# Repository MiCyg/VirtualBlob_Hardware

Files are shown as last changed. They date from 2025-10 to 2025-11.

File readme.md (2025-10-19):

# Virtual Blob Hardware


[← Back to main repository](https://github.com/MiCyg/VirtualBlob.git)

---

The device consists of three PCBs:
- `MainBoard` – microcontroller and peripheral interfaces
- `PowerBoard` – USB connector and battery charging circuit
- `LedBoard` – LED matrix driven by the MAX7219

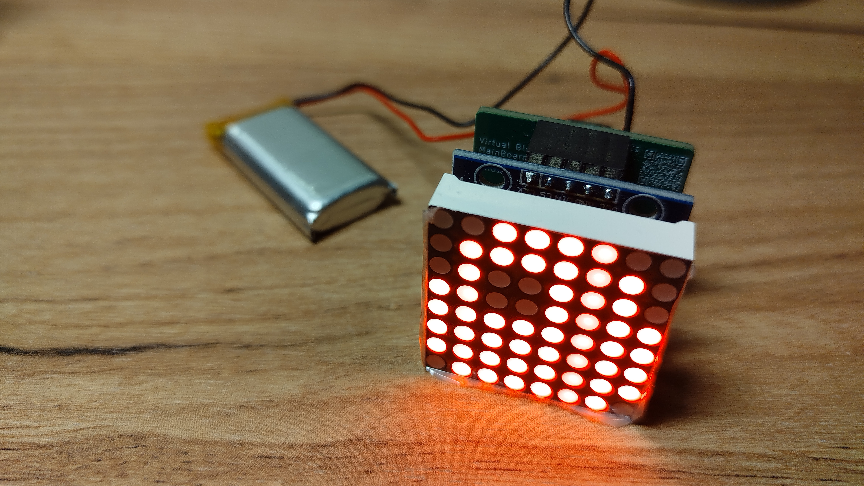
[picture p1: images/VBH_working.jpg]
Working example of Virtual Blob


Components on the boards:
- RP2040 microcontroller with SWD programming interface
- Accelerometer LIS3DH
- Capacitive touch sensor AT42QT1011
- Light sensor (LDR with resistor divider)
- Li-Po battery (LP852040)
- Battery charger MCP73811T

## Description

The `MainBoard` and `PowerBoard` are connected using a custom-designed `EdgeConn` board-to-board connector, allowing a 90° connection between the two.
Due to the small overall size and the position of the USB connector, I decided to use a ready-made LED matrix module. This approach saves valuable PCB space on the `MainBoard`, which is limited by the placement of the edge connector.

The device is designed to operate continuously from a Li-Po battery. Therefore, proper power management in sleep mode is crucial. To reduce power consumption, a high-side P-MOSFET switch is used to disconnect the accelerometer and light sensors when the system enters sleep mode. The capacitive touch sensor remains powered at all times, as it is responsible for waking up the device.

## Assembled Boards

<p align="center">
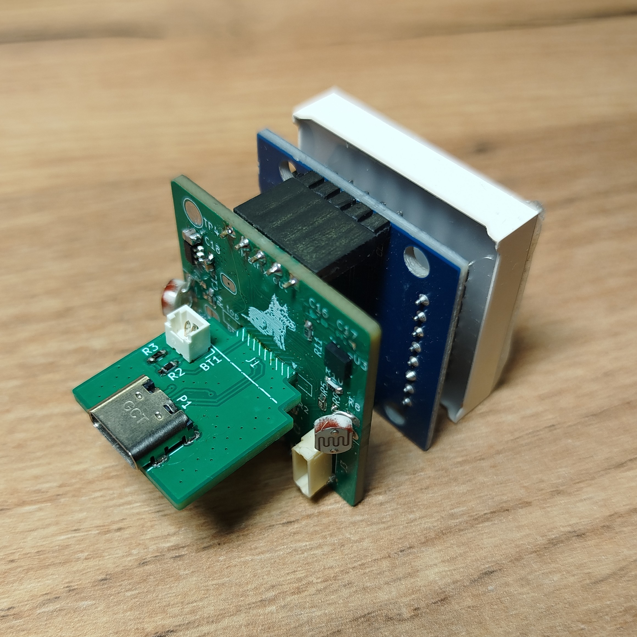
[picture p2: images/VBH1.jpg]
	
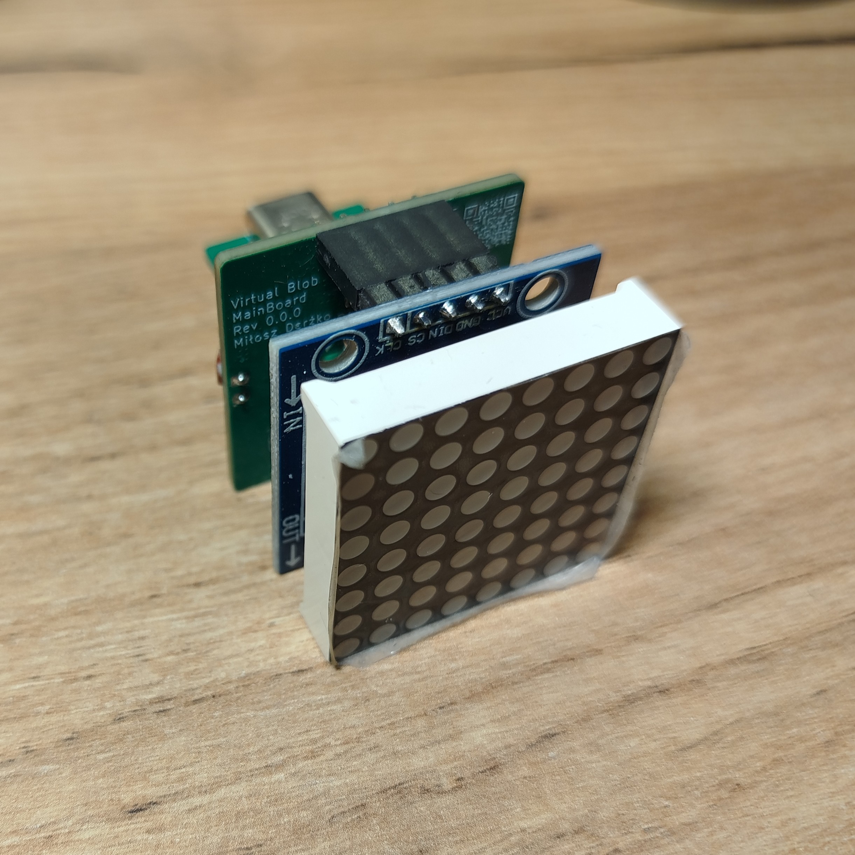
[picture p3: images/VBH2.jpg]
	
</p>

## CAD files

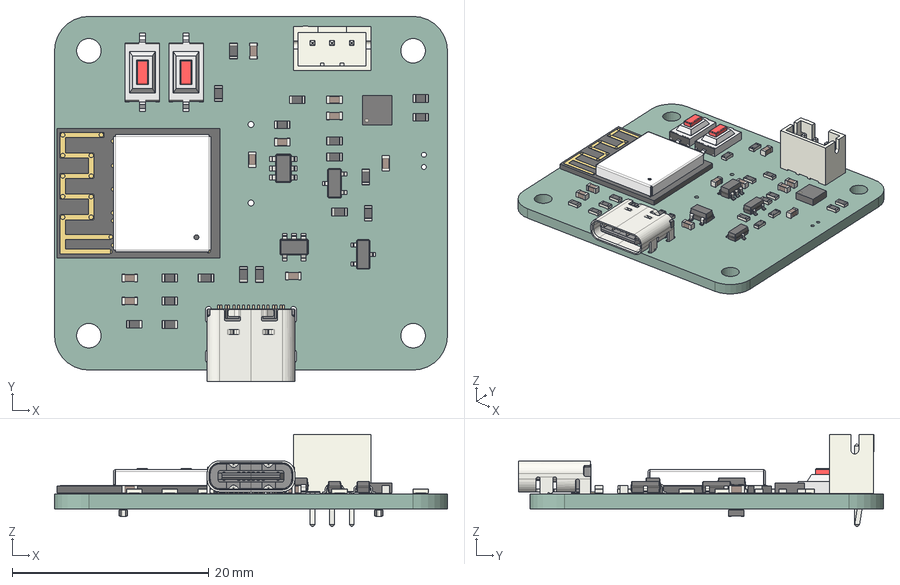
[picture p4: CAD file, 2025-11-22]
MainBoard/3d/VirtualBlob_MainBoard_0.4.0.step
40.0 x 37.2 x 9.40 mm
R_0603_1608Metric x 18
LGA-16_3x3mm_P0.5mm_LayoutBorder3x5y
SOT-23-5
SOT-23 x 2
C_0603_1608Metric x 9
JST_PH_B3B-PH-K_1x03_P2.00mm_Vertical
SW_SPST_CK_RS282G05A3 x 2
USB_C_Receptacle_GCT_USB4105-xx-A_16P_TopMnt_Horizontal
SOT-23-6
DFN1006.STEP^DFN1006.STEP_Submodel-SOD882_part_DesignRootModel_PCB_ ESP32-C3-MINI-1_V1(2)_PCB_ESP32-C3-MINI-1_V1
R0201_20210301.STEP^R0201_20210301.STEP_Submodel-R0201_part_ DesignRootModel_PCB_ESP32-C3-MINI-1_V1(2)_PCB_ESP32-C3-MINI-1_V1 x 3
placementOutline^Submodel-noModelForPart_MINI-ANT-TYPED-H_1968823293_ Submodel-MINI-ANT-TYPED-H_1968823293_part_DesignRootModel_PCB_ ESP32-C3-MINI-1_V1(2)_PCB_E
placementOutline-0^Submodel-noModelForPart_MINI-ANT-TYPED-H_1968823293_ Submodel-MINI-ANT-TYPED-H_1968823293_part_DesignRootModel_PCB_ ESP32-C3-MINI-1_V1(2)_PCB
placementOutline-1^Submodel-noModelForPart_MINI-ANT-TYPED-H_1968823293_ Submodel-MINI-ANT-TYPED-H_1968823293_part_DesignRootModel_PCB_ ESP32-C3-MINI-1_V1(2)_PCB
placementOutline-2^Submodel-noModelForPart_MINI-ANT-TYPED-H_1968823293_ Submodel-MINI-ANT-TYPED-H_1968823293_part_DesignRootModel_PCB_ ESP32-C3-MINI-1_V1(2)_PCB
placementOutline-3^Submodel-noModelForPart_MINI-ANT-TYPED-H_1968823293_ Submodel-MINI-ANT-TYPED-H_1968823293_part_DesignRootModel_PCB_ ESP32-C3-MINI-1_V1(2)_PCB
placementOutline-4^Submodel-noModelForPart_MINI-ANT-TYPED-H_1968823293_ Submodel-MINI-ANT-TYPED-H_1968823293_part_DesignRootModel_PCB_ ESP32-C3-MINI-1_V1(2)_PCB
placementOutline-5^Submodel-noModelForPart_MINI-ANT-TYPED-H_1968823293_ Submodel-MINI-ANT-TYPED-H_1968823293_part_DesignRootModel_PCB_ ESP32-C3-MINI-1_V1(2)_PCB
trace_4^Submodel-MINI-ANT-TYPED-H_1968823293_part_DesignRootModel_PCB_ ESP32-C3-MINI-1_V1(2)_PCB_ESP32-C3-MINI-1_V1
trace_1^Submodel-MINI-ANT-TYPED-H_1968823293_part_DesignRootModel_PCB_ ESP32-C3-MINI-1_V1(2)_PCB_ESP32-C3-MINI-1_V1
C0402_20210301.STEP^C0402_20210301.STEP_Submodel-C0402_part_ DesignRootModel_PCB_ESP32-C3-MINI-1_V1(2)_PCB_ESP32-C3-MINI-1_V1
C0201_20210301.STEP^C0201_20210301.STEP_Submodel-C0201_part_ DesignRootModel_PCB_ESP32-C3-MINI-1_V1(2)_PCB_ESP32-C3-MINI-1_V1 x 11
L0201_20210301.STEP^L0201_20210301.STEP_Submodel-L0201_part_ DesignRootModel_PCB_ESP32-C3-MINI-1_V1(2)_PCB_ESP32-C3-MINI-1_V1 x 2
XTAL3225_20210301.STEP^XTAL3225_20210301.STEP_Submodel-XTAL3225_part_ DesignRootModel_PCB_ESP32-C3-MINI-1_V1(2)_PCB_ESP32-C3-MINI-1_V1
ESP32-C3_20210301.STEP^ESP32-C3_20210301.STEP_Submodel-QFN32_0P5_5_ part_DesignRootModel_PCB_ESP32-C3-MINI-1_V1(2)_PCB_ESP32-C3-MINI-1_V1
uid__4^DesignRootModel_PCB_ESP32-C3-MINI-1_V1(2)_PCB_ESP32-C3-MINI-1_ V1
uid__4-22^DesignRootModel_PCB_ESP32-C3-MINI-1_V1(2)_PCB_ ESP32-C3-MINI-1_V1
uid__4-23^DesignRootModel_PCB_ESP32-C3-MINI-1_V1(2)_PCB_ ESP32-C3-MINI-1_V1
uid__4-24^DesignRootModel_PCB_ESP32-C3-MINI-1_V1(2)_PCB_ ESP32-C3-MINI-1_V1
uid__4-25^DesignRootModel_PCB_ESP32-C3-MINI-1_V1(2)_PCB_ ESP32-C3-MINI-1_V1
uid__4-26^DesignRootModel_PCB_ESP32-C3-MINI-1_V1(2)_PCB_ ESP32-C3-MINI-1_V1
uid__4-27^DesignRootModel_PCB_ESP32-C3-MINI-1_V1(2)_PCB_ ESP32-C3-MINI-1_V1
uid__4-28^DesignRootModel_PCB_ESP32-C3-MINI-1_V1(2)_PCB_ ESP32-C3-MINI-1_V1
uid__4-29^DesignRootModel_PCB_ESP32-C3-MINI-1_V1(2)_PCB_ ESP32-C3-MINI-1_V1
uid__4-30^DesignRootModel_PCB_ESP32-C3-MINI-1_V1(2)_PCB_ ESP32-C3-MINI-1_V1
uid__4-31^DesignRootModel_PCB_ESP32-C3-MINI-1_V1(2)_PCB_ ESP32-C3-MINI-1_V1
uid__4-32^DesignRootModel_PCB_ESP32-C3-MINI-1_V1(2)_PCB_ ESP32-C3-MINI-1_V1
uid__4-33^DesignRootModel_PCB_ESP32-C3-MINI-1_V1(2)_PCB_ ESP32-C3-MINI-1_V1
uid__4-34^DesignRootModel_PCB_ESP32-C3-MINI-1_V1(2)_PCB_ ESP32-C3-MINI-1_V1
uid__4-35^DesignRootModel_PCB_ESP32-C3-MINI-1_V1(2)_PCB_ ESP32-C3-MINI-1_V1
uid__4-36^DesignRootModel_PCB_ESP32-C3-MINI-1_V1(2)_PCB_ ESP32-C3-MINI-1_V1
uid__4-37^DesignRootModel_PCB_ESP32-C3-MINI-1_V1(2)_PCB_ ESP32-C3-MINI-1_V1
uid__4-38^DesignRootModel_PCB_ESP32-C3-MINI-1_V1(2)_PCB_ ESP32-C3-MINI-1_V1
uid__4-39^DesignRootModel_PCB_ESP32-C3-MINI-1_V1(2)_PCB_ ESP32-C3-MINI-1_V1
uid__4-40^DesignRootModel_PCB_ESP32-C3-MINI-1_V1(2)_PCB_ ESP32-C3-MINI-1_V1
uid__4-41^DesignRootModel_PCB_ESP32-C3-MINI-1_V1(2)_PCB_ ESP32-C3-MINI-1_V1
uid__4-42^DesignRootModel_PCB_ESP32-C3-MINI-1_V1(2)_PCB_ ESP32-C3-MINI-1_V1
uid__4-43^DesignRootModel_PCB_ESP32-C3-MINI-1_V1(2)_PCB_ ESP32-C3-MINI-1_V1
uid__4-44^DesignRootModel_PCB_ESP32-C3-MINI-1_V1(2)_PCB_ ESP32-C3-MINI-1_V1
uid__4-45^DesignRootModel_PCB_ESP32-C3-MINI-1_V1(2)_PCB_ ESP32-C3-MINI-1_V1
uid__4-46^DesignRootModel_PCB_ESP32-C3-MINI-1_V1(2)_PCB_ ESP32-C3-MINI-1_V1
uid__4-47^DesignRootModel_PCB_ESP32-C3-MINI-1_V1(2)_PCB_ ESP32-C3-MINI-1_V1
uid__4-48^DesignRootModel_PCB_ESP32-C3-MINI-1_V1(2)_PCB_ ESP32-C3-MINI-1_V1
uid__4-49^DesignRootModel_PCB_ESP32-C3-MINI-1_V1(2)_PCB_ ESP32-C3-MINI-1_V1
uid__4-50^DesignRootModel_PCB_ESP32-C3-MINI-1_V1(2)_PCB_ ESP32-C3-MINI-1_V1
uid__4-51^DesignRootModel_PCB_ESP32-C3-MINI-1_V1(2)_PCB_ ESP32-C3-MINI-1_V1
uid__4-52^DesignRootModel_PCB_ESP32-C3-MINI-1_V1(2)_PCB_ ESP32-C3-MINI-1_V1
uid__4-53^DesignRootModel_PCB_ESP32-C3-MINI-1_V1(2)_PCB_ ESP32-C3-MINI-1_V1
uid__4-54^DesignRootModel_PCB_ESP32-C3-MINI-1_V1(2)_PCB_ ESP32-C3-MINI-1_V1
uid__4-55^DesignRootModel_PCB_ESP32-C3-MINI-1_V1(2)_PCB_ ESP32-C3-MINI-1_V1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

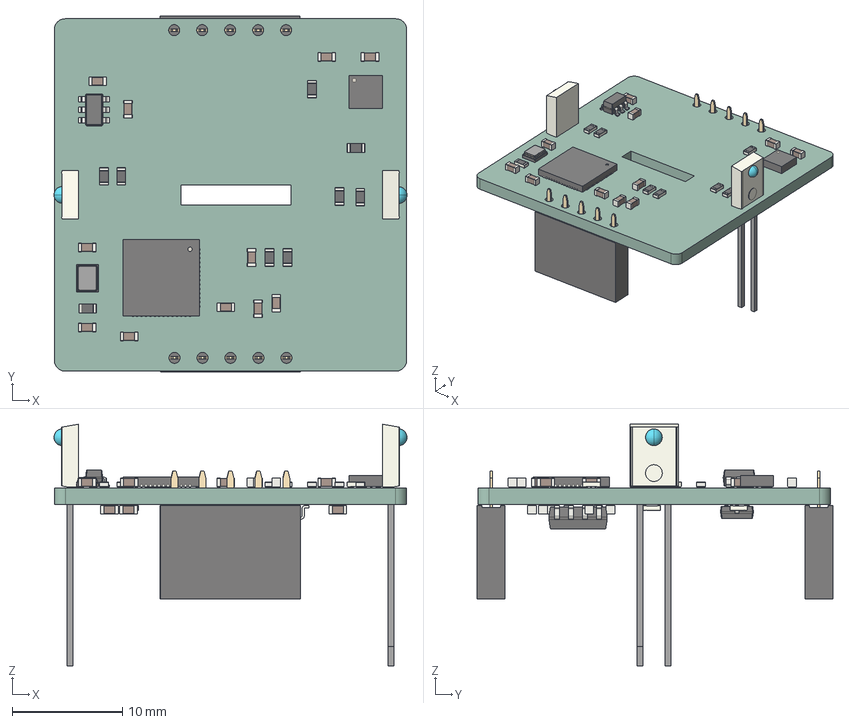
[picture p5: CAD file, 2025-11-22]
MainBoard/3d/VirtualBlob_MainBoard_0.0.0.step
32.0 x 32.3 x 21.9 mm
R_0603_1608Metric x 11
Crystal_SMD_2520-4Pin_2.5x2.0mm
C_0603_1608Metric x 18
LGA-16_3x3mm_P0.5mm_LayoutBorder3x5y
SOT-23-6
Osram_LPT80A x 2
QFN-56-1EP_7x7mm_P0.4mm_EP3.2x3.2mm
SOIC-8_5.3x5.3mm_P1.27mm
PinSocket_1x05_P2.54mm_Vertical x 2
SOT-23
mainboard_PCB

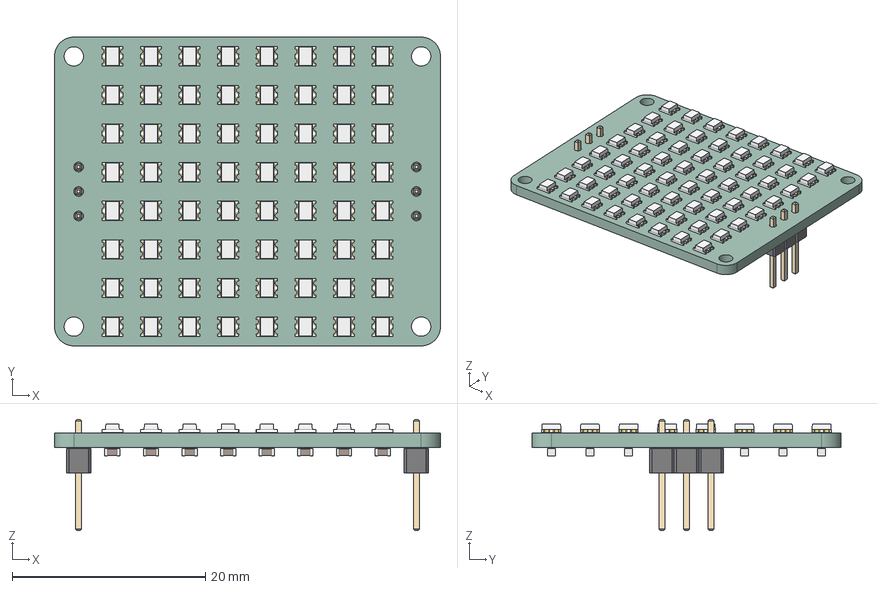
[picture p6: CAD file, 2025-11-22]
MatrixBoard/3d/VirtualBlob_MatrixBoard_0.0.0.step
40.0 x 32.0 x 11.5 mm
WS2812-2020 x 64
C_0603_1608Metric x 64
PinHeader_1x03_P2.54mm_Vertical x 2
MatrixBoard_PCB

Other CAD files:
MainBoard/3d/VirtualBlob_MainBoard_0.3.0.step
MatrixBoard/3d/MatrixBoard.step

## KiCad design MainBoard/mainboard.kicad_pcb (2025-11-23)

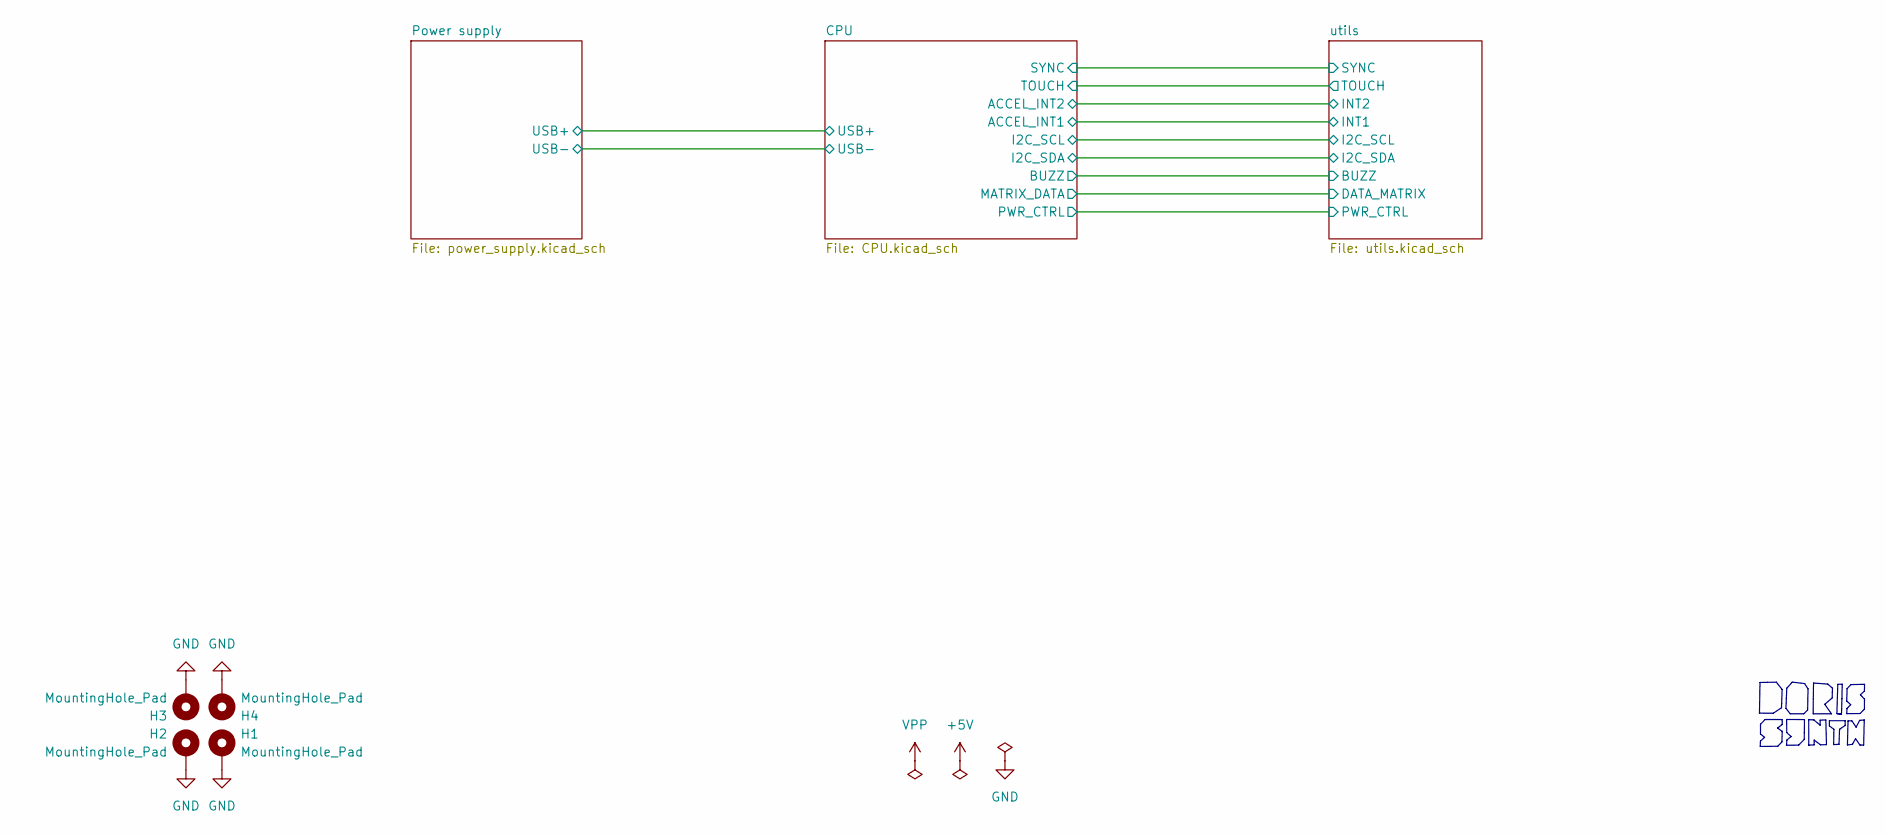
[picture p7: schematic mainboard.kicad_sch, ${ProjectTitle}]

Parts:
H1, H2, H3, H4: MountingHole_Pad; MountingHole_2.5mm

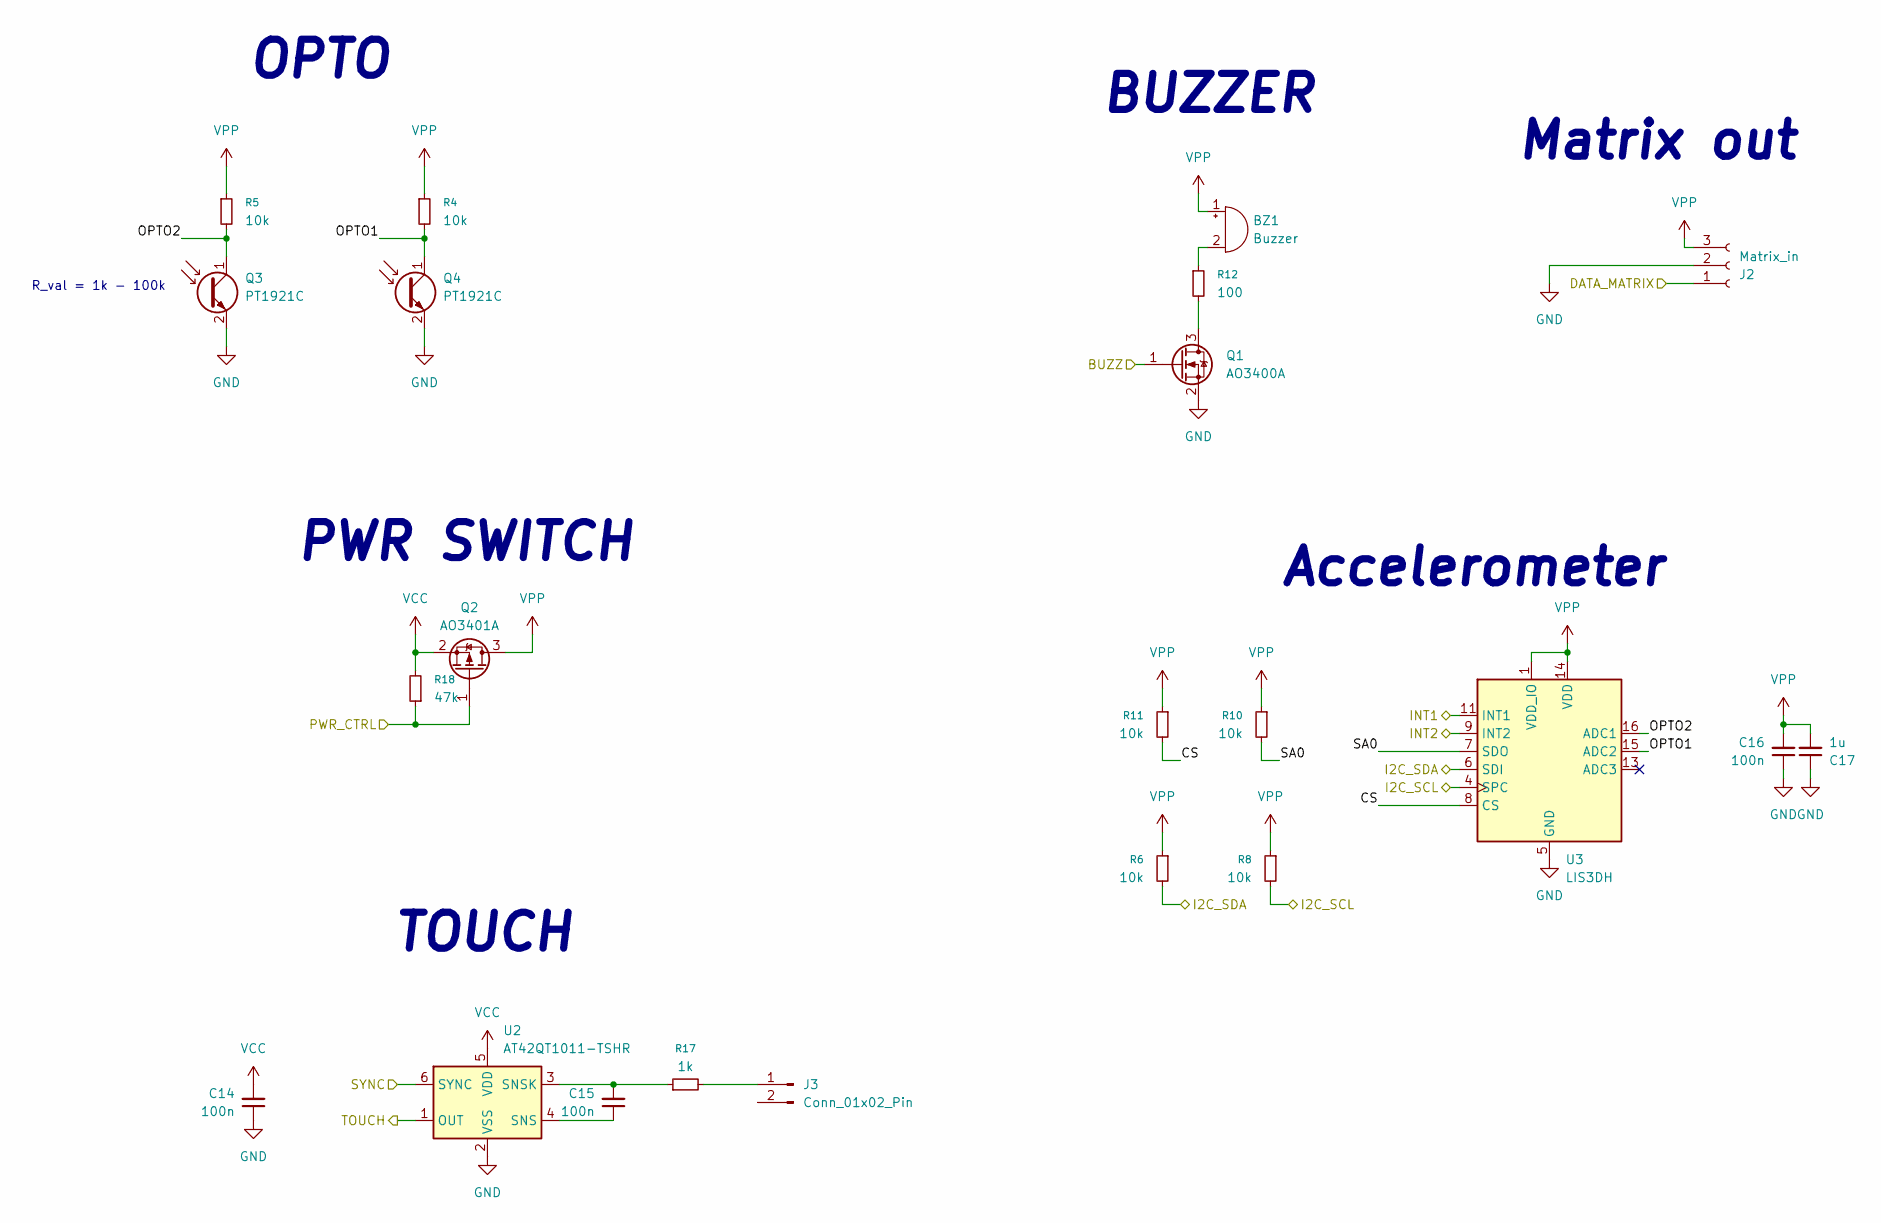
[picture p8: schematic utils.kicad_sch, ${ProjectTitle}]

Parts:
BZ1: Buzzer; Buzzer_SMD_5020
C14, C15, C16: 100n; C_0603_1608Metric_Pad1.08x0.95mm_HandSolder
C17: 1u; C_0603_1608Metric_Pad1.08x0.95mm_HandSolder
J2: Matrix_in; JST_PH_B3B-PH-K_1x03_P2.00mm_Vertical
J3: Conn_01x02_Pin; FW-UU_04_08_15
Q1: AO3400A; SOT-23
Q2: AO3401A; SOT-23
Q3, Q4: PT1921C; D_0603_1608Metric_Pad1.05x0.95mm_HandSolder
R4, R5, R6, R8, R10, R11: 10k; R_0603_1608Metric_Pad0.98x0.95mm_HandSolder
R12: 100; R_0603_1608Metric_Pad0.98x0.95mm_HandSolder
R17: 1k; R_0603_1608Metric_Pad0.98x0.95mm_HandSolder
R18: 47k; R_0603_1608Metric_Pad0.98x0.95mm_HandSolder
U2: AT42QT1011-TSHR; SOT-23-6
U3: LIS3DH; LGA-16_3x3mm_P0.5mm_LayoutBorder3x5y

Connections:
/CPU/ACCEL_INT1: U3.11 (INT1); also elsewhere on the board
/CPU/ACCEL_INT2: U3.9 (INT2); also elsewhere on the board
/CPU/BUZZ: Q1.1 (G); also elsewhere on the board
/CPU/I2C_SCL: R8.2, U3.4 (SPC); also elsewhere on the board
/CPU/I2C_SDA: R6.2, U3.6 (SDI); also elsewhere on the board
/CPU/MATRIX_DATA: J2.1; also elsewhere on the board
/CPU/PWR_CTRL: Q2.1 (G), R18.1; also elsewhere on the board
/CPU/SYNC: U2.6 (SYNC); also elsewhere on the board
/CPU/TOUCH: U2.1 (OUT); also elsewhere on the board
/utils/CS: R11.2, U3.8 (CS)
/utils/OPTO1: Q4.1 (C), R4.2, U3.15 (ADC2)
/utils/OPTO2: Q3.1 (C), R5.2, U3.16 (ADC1)
/utils/SA0: R10.2, U3.7 (SDO)
GND: C14.1, C16.1, C17.1, J2.2, Q1.2 (S), Q3.2 (E), Q4.2 (E), U2.2 (VSS), U3.5 (GND), U3.10 (GND), U3.12 (GND); also elsewhere on the board
unnamed: BZ1.2 (-), R12.1
unnamed: J3.1, R17.2
unnamed: Q1.3 (D), R12.2
unnamed: C15.1, U2.4 (SNS)
unnamed: C15.2, R17.1, U2.3 (SNSK)
VCC: C14.2, Q2.2 (S), R18.2, U2.5 (VDD); also elsewhere on the board
VPP: BZ1.1 (+), C16.2, C17.2, J2.3, Q2.3 (D), R4.1, R5.1, R6.1, R8.1, R10.1, R11.1, U3.1 (VDD_IO), U3.14 (VDD)

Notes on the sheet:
OPTO
R_val = 1k - 100k
Matrix out
PWR SWITCH
BUZZER
TOUCH
Accelerometer

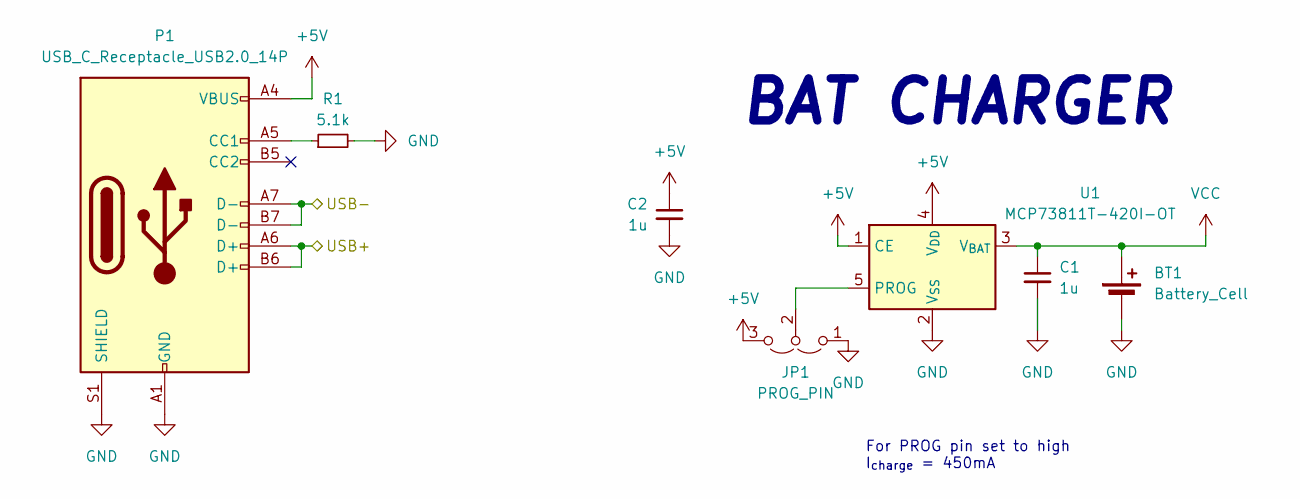
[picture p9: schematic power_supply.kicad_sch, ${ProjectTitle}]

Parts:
BT1: Battery_Cell; Molex_PicoBlade_53047-0210_1x02_P1.25mm_Vertical
C1, C2: 1u; C_0603_1608Metric_Pad1.08x0.95mm_HandSolder
JP1: PROG_PIN; SolderJumper-3_P1.3mm_Open_RoundedPad1.0x1.5mm
P1: USB_C_Receptacle_USB2.0_14P; USB_C_Receptacle_G-Switch_GT-USB-7010ASV
R1: 5.1k; R_0603_1608Metric_Pad0.98x0.95mm_HandSolder
U1: MCP73811T-420I-OT; SOT-23-5

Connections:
+5V: C2.1, JP1.3 (B), P1.A4 (VBUS), P1.A9 (VBUS), P1.B4 (VBUS), P1.B9 (VBUS), U1.1 (CE), U1.4 (V_{DD})
/CPU/USB+: P1.A6 (D+), P1.B6 (D+); also elsewhere on the board
/CPU/USB-: P1.A7 (D-), P1.B7 (D-); also elsewhere on the board
GND: BT1.2 (-), C1.2, C2.2, JP1.1 (A), P1.A1 (GND), P1.A12 (GND), P1.B1 (GND), P1.B12 (GND), P1.S1 (SHIELD), R1.2, U1.2 (V_{SS}); also elsewhere on the board
unnamed: JP1.2 (C), U1.5 (PROG)
unnamed: P1.A5 (CC1), R1.1
VCC: BT1.1 (+), C1.1, U1.3 (V_{BAT}); also elsewhere on the board

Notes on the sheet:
BAT CHARGER
For PROG pin set to high I_{charge} = 450mA

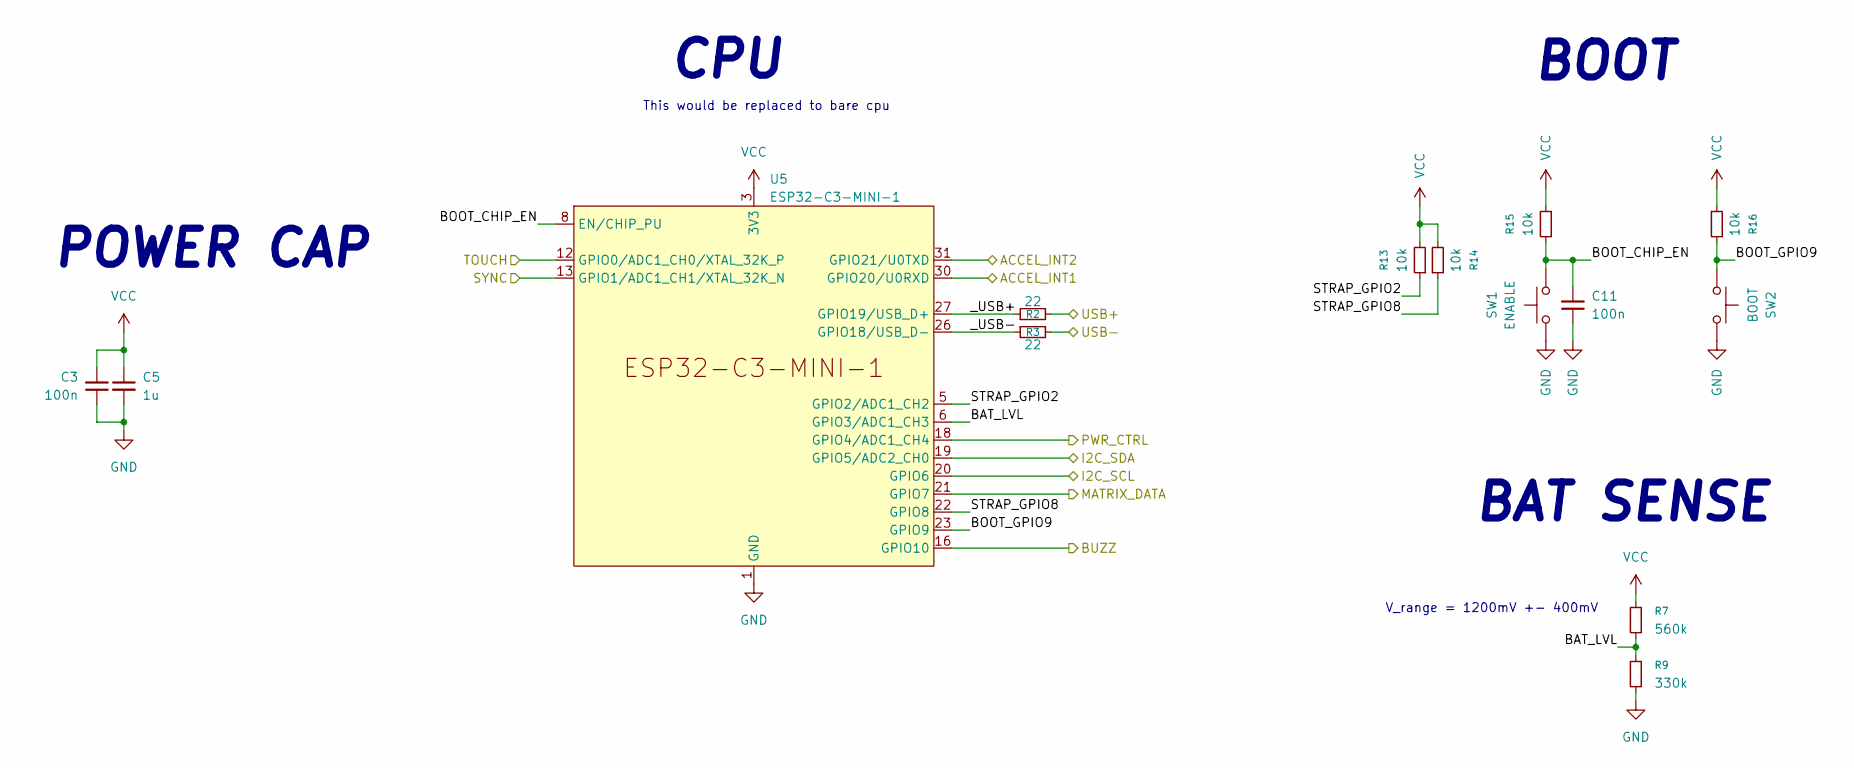
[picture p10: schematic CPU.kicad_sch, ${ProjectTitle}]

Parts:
C3, C11: 100n; C_0603_1608Metric_Pad1.08x0.95mm_HandSolder
C5: 1u; C_0603_1608Metric_Pad1.08x0.95mm_HandSolder
R2, R3: 22; R_0603_1608Metric_Pad0.98x0.95mm_HandSolder
R7: 560k; R_0603_1608Metric_Pad0.98x0.95mm_HandSolder
R9: 330k; R_0603_1608Metric_Pad0.98x0.95mm_HandSolder
R13, R14, R15, R16: 10k; R_0603_1608Metric_Pad0.98x0.95mm_HandSolder
SW1: ENABLE; SW_SPST_CK_RS282G05A3
SW2: BOOT; SW_SPST_CK_RS282G05A3
U5: ESP32-C3-MINI-1

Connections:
/CPU/ACCEL_INT1: U5.30 (GPIO20/U0RXD); also elsewhere on the board
/CPU/ACCEL_INT2: U5.31 (GPIO21/U0TXD); also elsewhere on the board
/CPU/BAT_LVL: R7.2, R9.1, U5.6 (GPIO3/ADC1_CH3)
/CPU/BOOT_CHIP_EN: C11.2, R15.2, SW1.2, U5.8 (EN/CHIP_PU)
/CPU/BOOT_GPIO9: R16.2, SW2.2, U5.23 (GPIO9)
/CPU/BUZZ: U5.16 (GPIO10); also elsewhere on the board
/CPU/I2C_SCL: U5.20 (GPIO6); also elsewhere on the board
/CPU/I2C_SDA: U5.19 (GPIO5/ADC2_CH0); also elsewhere on the board
/CPU/MATRIX_DATA: U5.21 (GPIO7); also elsewhere on the board
/CPU/PWR_CTRL: U5.18 (GPIO4/ADC1_CH4); also elsewhere on the board
/CPU/STRAP_GPIO2: R13.1, U5.5 (GPIO2/ADC1_CH2)
/CPU/STRAP_GPIO8: R14.1, U5.22 (GPIO8)
/CPU/SYNC: U5.13 (GPIO1/ADC1_CH1/XTAL_32K_N); also elsewhere on the board
/CPU/TOUCH: U5.12 (GPIO0/ADC1_CH0/XTAL_32K_P); also elsewhere on the board
/CPU/USB+: R2.2; also elsewhere on the board
/CPU/USB-: R3.2; also elsewhere on the board
/CPU/_USB+: R2.1, U5.27 (GPIO19/USB_D+)
/CPU/_USB-: R3.1, U5.26 (GPIO18/USB_D-)
GND: C3.1, C5.2, C11.1, R9.2, SW1.1, SW2.1, U5.1 (GND), U5.2 (GND), U5.11 (GND), U5.14 (GND), U5.36 (GND), U5.37 (GND), U5.38 (GND), U5.39 (GND), U5.40 (GND), U5.41 (GND), U5.42 (GND), U5.43 (GND), U5.44 (GND), U5.45 (GND), U5.46 (GND), U5.47 (GND), U5.48 (GND), U5.49 (GND), U5.50 (GND), U5.51 (GND), U5.52 (GND), U5.53 (GND); also elsewhere on the board
VCC: C3.2, C5.1, R7.1, R13.2, R14.2, R15.1, R16.1, U5.3 (3V3); also elsewhere on the board

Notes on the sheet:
CPU
BOOT
This would be replaced to bare cpu
BAT SENSE
POWER CAP
V_range = 1200mV +- 400mV

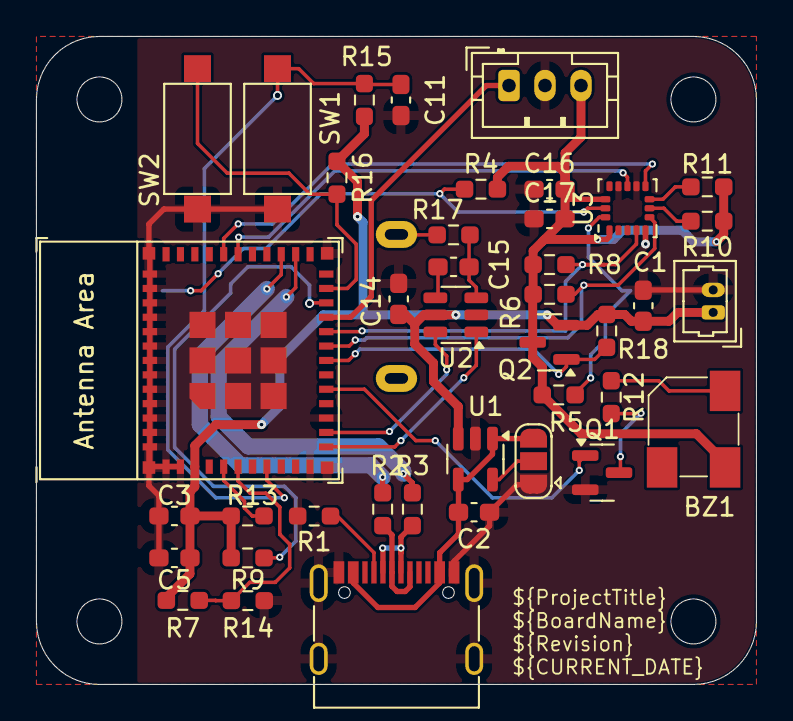
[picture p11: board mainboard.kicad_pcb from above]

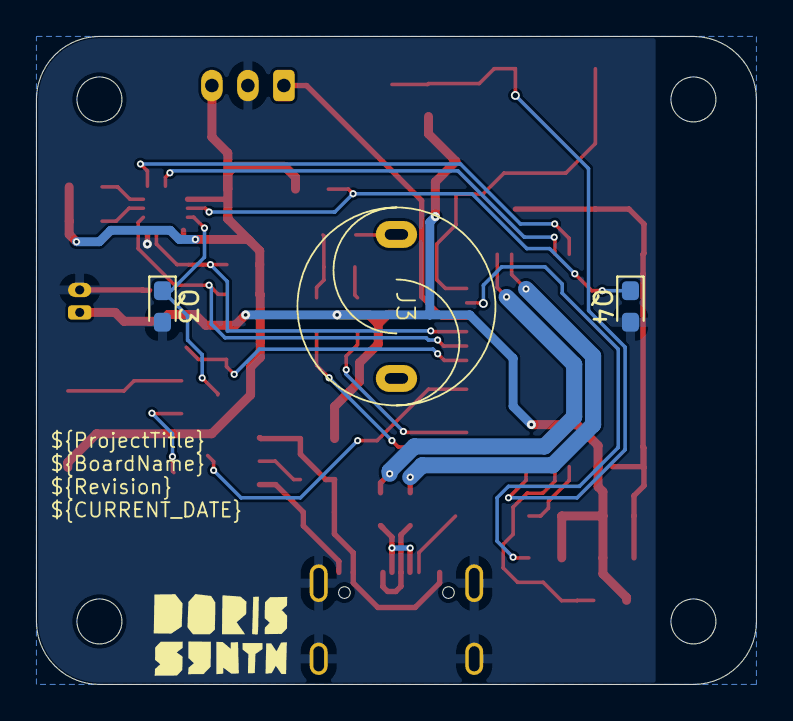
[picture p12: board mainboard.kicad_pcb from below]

Board: 2 copper layers, 40.0 x 36.0 mm, 47 parts (3 on the bottom side), 33 nets.

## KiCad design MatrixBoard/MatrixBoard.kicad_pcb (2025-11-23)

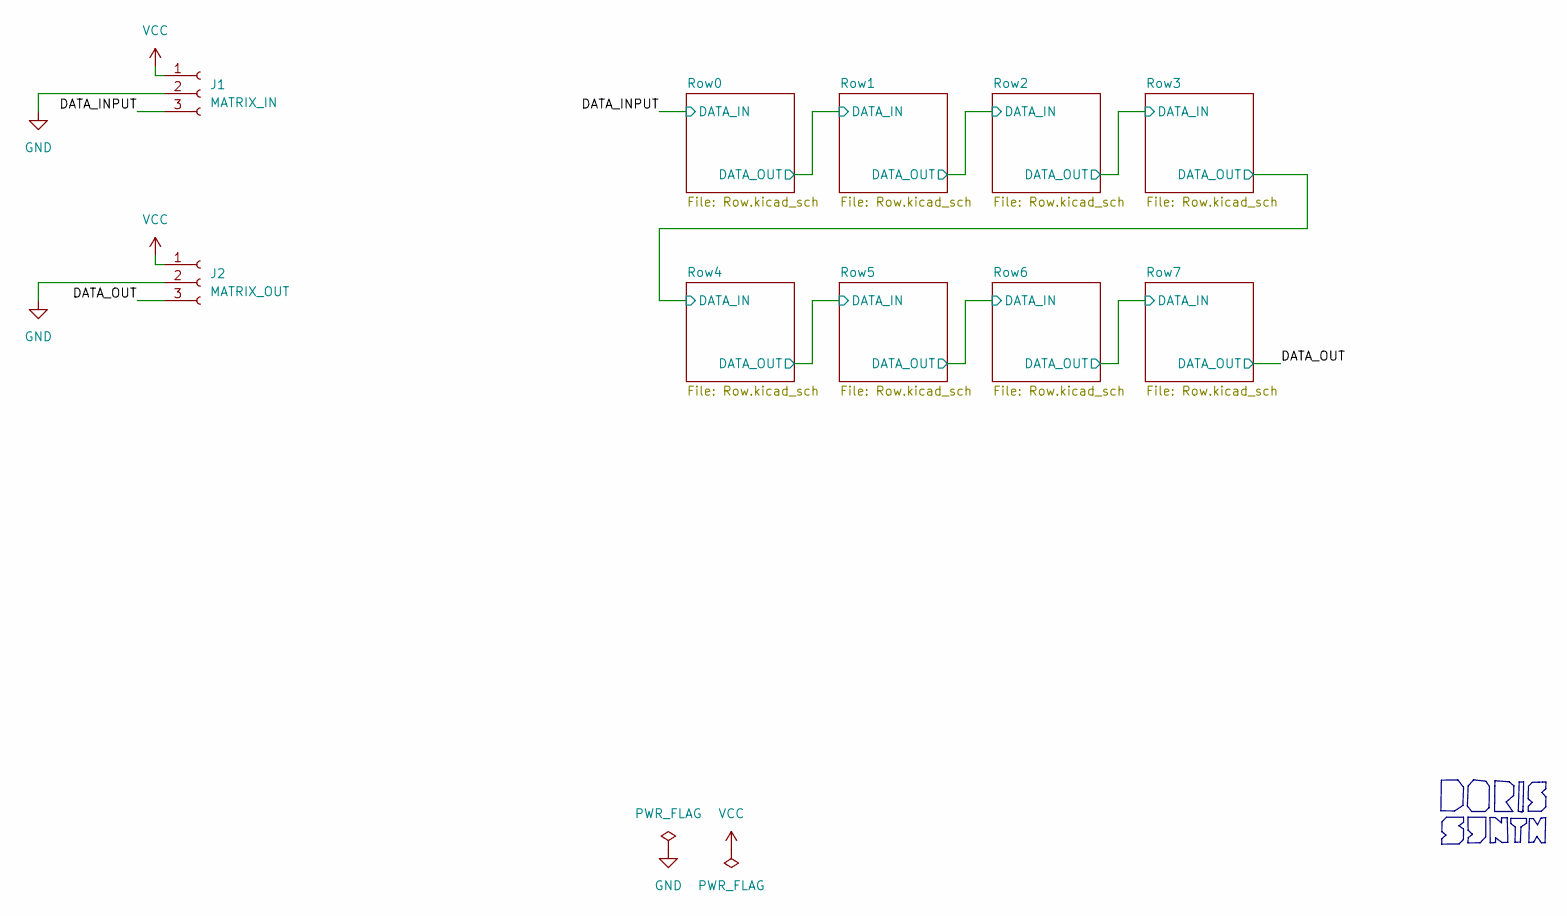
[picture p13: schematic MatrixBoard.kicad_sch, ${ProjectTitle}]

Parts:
J1: MATRIX_IN; PinHeader_1x03_P2.54mm_Vertical
J2: MATRIX_OUT; PinHeader_1x03_P2.54mm_Vertical

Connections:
/DATA_INPUT: J1.3; also elsewhere on the board
/DATA_OUT: J2.3; also elsewhere on the board
GND: J1.2, J2.2; also elsewhere on the board
VCC: J1.1, J2.1; also elsewhere on the board

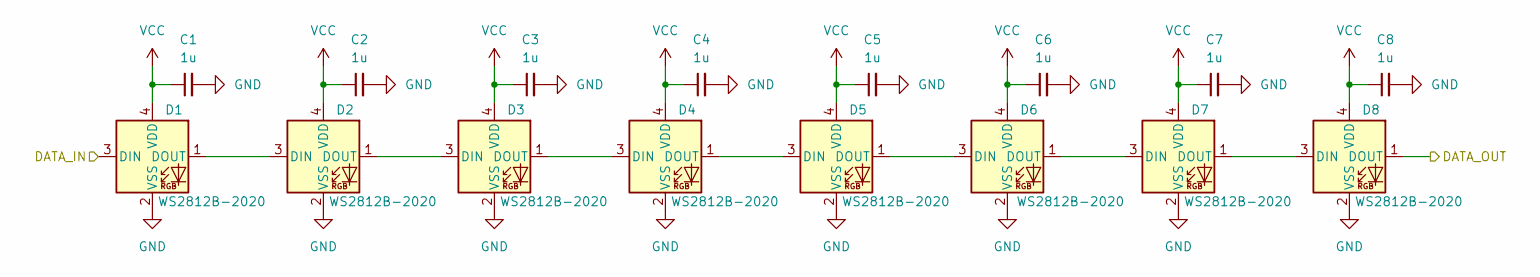
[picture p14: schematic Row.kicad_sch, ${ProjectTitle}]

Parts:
C1, C2, C3, C4, C5, C6, C7, C8: 1u; C_0603_1608Metric_Pad1.08x0.95mm_HandSolder
D1, D2, D3, D4, D5, D6, D7, D8: WS2812B-2020; LED_WS2812B-2020_PLCC4_2.0x2.0mm

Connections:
/DATA_INPUT: D1.3 (DIN); also elsewhere on the board
/Row0/DATA_OUT: D8.1 (DOUT); also elsewhere on the board
GND: C1.2, C2.2, C3.2, C4.2, C5.2, C6.2, C7.2, C8.2, D1.2 (VSS), D2.2 (VSS), D3.2 (VSS), D4.2 (VSS), D5.2 (VSS), D6.2 (VSS), D7.2 (VSS), D8.2 (VSS); also elsewhere on the board
unnamed: D1.1 (DOUT), D2.3 (DIN)
unnamed: D2.1 (DOUT), D3.3 (DIN)
unnamed: D3.1 (DOUT), D4.3 (DIN)
unnamed: D4.1 (DOUT), D5.3 (DIN)
unnamed: D5.1 (DOUT), D6.3 (DIN)
unnamed: D6.1 (DOUT), D7.3 (DIN)
unnamed: D7.1 (DOUT), D8.3 (DIN)
VCC: C1.1, C2.1, C3.1, C4.1, C5.1, C6.1, C7.1, C8.1, D1.4 (VDD), D2.4 (VDD), D3.4 (VDD), D4.4 (VDD), D5.4 (VDD), D6.4 (VDD), D7.4 (VDD), D8.4 (VDD); also elsewhere on the board

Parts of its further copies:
C9, C10, C11, C12, C13, C14, C15, C16, C17, C18, C19, C20, C21, C22, C23, C24, C25, C26, C27, C28, C29, C30, C31, C32, C33, C34, C35, C36, C37, C38, C39, C40, C41, C42, C43, C44, C45, C46, C47, C48, C49, C50, C51, C52, C53, C54, C55, C56, C57, C58, C59, C60, C61, C62, C63, C64: 1u; C_0603_1608Metric_Pad1.08x0.95mm_HandSolder
D9, D10, D11, D12, D13, D14, D15, D16, D17, D18, D19, D20, D21, D22, D23, D24, D25, D26, D27, D28, D29, D30, D31, D32, D33, D34, D35, D36, D37, D38, D39, D40, D41, D42, D43, D44, D45, D46, D47, D48, D49, D50, D51, D52, D53, D54, D55, D56, D57, D58, D59, D60, D61, D62, D63, D64: WS2812B-2020; LED_WS2812B-2020_PLCC4_2.0x2.0mm

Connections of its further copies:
/DATA_OUT: D64.1 (DOUT); also elsewhere on the board
/Row0/DATA_OUT: D9.3 (DIN); also elsewhere on the board
/Row1/DATA_OUT: D16.1 (DOUT), D17.3 (DIN)
/Row2/DATA_OUT: D24.1 (DOUT), D25.3 (DIN)
/Row3/DATA_OUT: D32.1 (DOUT), D33.3 (DIN)
/Row4/DATA_OUT: D40.1 (DOUT), D41.3 (DIN)
/Row5/DATA_OUT: D48.1 (DOUT), D49.3 (DIN)
/Row6/DATA_OUT: D56.1 (DOUT), D57.3 (DIN)
GND: C9.2, C10.2, C11.2, C12.2, C13.2, C14.2, C15.2, C16.2, C17.2, C18.2, C19.2, C20.2, C21.2, C22.2, C23.2, C24.2, C25.2, C26.2, C27.2, C28.2, C29.2, C30.2, C31.2, C32.2, C33.2, C34.2, C35.2, C36.2, C37.2, C38.2, C39.2, C40.2, C41.2, C42.2, C43.2, C44.2, C45.2, C46.2, C47.2, C48.2, C49.2, C50.2, C51.2, C52.2, C53.2, C54.2, C55.2, C56.2, C57.2, C58.2, C59.2, C60.2, C61.2, C62.2, C63.2, C64.2, D9.2 (VSS), D10.2 (VSS), D11.2 (VSS), D12.2 (VSS), D13.2 (VSS), D14.2 (VSS), D15.2 (VSS), D16.2 (VSS), D17.2 (VSS), D18.2 (VSS), D19.2 (VSS), D20.2 (VSS), D21.2 (VSS), D22.2 (VSS), D23.2 (VSS), D24.2 (VSS), D25.2 (VSS), D26.2 (VSS), D27.2 (VSS), D28.2 (VSS), D29.2 (VSS), D30.2 (VSS), D31.2 (VSS), D32.2 (VSS), D33.2 (VSS), D34.2 (VSS), D35.2 (VSS), D36.2 (VSS), D37.2 (VSS), D38.2 (VSS), D39.2 (VSS), D40.2 (VSS), D41.2 (VSS), D42.2 (VSS), D43.2 (VSS), D44.2 (VSS), D45.2 (VSS), D46.2 (VSS), D47.2 (VSS), D48.2 (VSS), D49.2 (VSS), D50.2 (VSS), D51.2 (VSS), D52.2 (VSS), D53.2 (VSS), D54.2 (VSS), D55.2 (VSS), D56.2 (VSS), D57.2 (VSS), D58.2 (VSS), D59.2 (VSS), D60.2 (VSS), D61.2 (VSS), D62.2 (VSS), D63.2 (VSS), D64.2 (VSS); also elsewhere on the board
unnamed: D9.1 (DOUT), D10.3 (DIN)
unnamed: D10.1 (DOUT), D11.3 (DIN)
unnamed: D11.1 (DOUT), D12.3 (DIN)
unnamed: D12.1 (DOUT), D13.3 (DIN)
unnamed: D13.1 (DOUT), D14.3 (DIN)
unnamed: D14.1 (DOUT), D15.3 (DIN)
unnamed: D15.1 (DOUT), D16.3 (DIN)
unnamed: D17.1 (DOUT), D18.3 (DIN)
unnamed: D18.1 (DOUT), D19.3 (DIN)
unnamed: D19.1 (DOUT), D20.3 (DIN)
unnamed: D20.1 (DOUT), D21.3 (DIN)
unnamed: D21.1 (DOUT), D22.3 (DIN)
unnamed: D22.1 (DOUT), D23.3 (DIN)
unnamed: D23.1 (DOUT), D24.3 (DIN)
unnamed: D25.1 (DOUT), D26.3 (DIN)
unnamed: D26.1 (DOUT), D27.3 (DIN)
unnamed: D27.1 (DOUT), D28.3 (DIN)
unnamed: D28.1 (DOUT), D29.3 (DIN)
unnamed: D29.1 (DOUT), D30.3 (DIN)
unnamed: D30.1 (DOUT), D31.3 (DIN)
unnamed: D31.1 (DOUT), D32.3 (DIN)
unnamed: D33.1 (DOUT), D34.3 (DIN)
unnamed: D34.1 (DOUT), D35.3 (DIN)
unnamed: D35.1 (DOUT), D36.3 (DIN)
unnamed: D36.1 (DOUT), D37.3 (DIN)
unnamed: D37.1 (DOUT), D38.3 (DIN)
unnamed: D38.1 (DOUT), D39.3 (DIN)
unnamed: D39.1 (DOUT), D40.3 (DIN)
unnamed: D41.1 (DOUT), D42.3 (DIN)
unnamed: D42.1 (DOUT), D43.3 (DIN)
unnamed: D43.1 (DOUT), D44.3 (DIN)
unnamed: D44.1 (DOUT), D45.3 (DIN)
unnamed: D45.1 (DOUT), D46.3 (DIN)
unnamed: D46.1 (DOUT), D47.3 (DIN)
unnamed: D47.1 (DOUT), D48.3 (DIN)
unnamed: D49.1 (DOUT), D50.3 (DIN)
unnamed: D50.1 (DOUT), D51.3 (DIN)
unnamed: D51.1 (DOUT), D52.3 (DIN)
unnamed: D52.1 (DOUT), D53.3 (DIN)
unnamed: D53.1 (DOUT), D54.3 (DIN)
unnamed: D54.1 (DOUT), D55.3 (DIN)
unnamed: D55.1 (DOUT), D56.3 (DIN)
unnamed: D57.1 (DOUT), D58.3 (DIN)
unnamed: D58.1 (DOUT), D59.3 (DIN)
unnamed: D59.1 (DOUT), D60.3 (DIN)
unnamed: D60.1 (DOUT), D61.3 (DIN)
unnamed: D61.1 (DOUT), D62.3 (DIN)
unnamed: D62.1 (DOUT), D63.3 (DIN)
unnamed: D63.1 (DOUT), D64.3 (DIN)
VCC: C9.1, C10.1, C11.1, C12.1, C13.1, C14.1, C15.1, C16.1, C17.1, C18.1, C19.1, C20.1, C21.1, C22.1, C23.1, C24.1, C25.1, C26.1, C27.1, C28.1, C29.1, C30.1, C31.1, C32.1, C33.1, C34.1, C35.1, C36.1, C37.1, C38.1, C39.1, C40.1, C41.1, C42.1, C43.1, C44.1, C45.1, C46.1, C47.1, C48.1, C49.1, C50.1, C51.1, C52.1, C53.1, C54.1, C55.1, C56.1, C57.1, C58.1, C59.1, C60.1, C61.1, C62.1, C63.1, C64.1, D9.4 (VDD), D10.4 (VDD), D11.4 (VDD), D12.4 (VDD), D13.4 (VDD), D14.4 (VDD), D15.4 (VDD), D16.4 (VDD), D17.4 (VDD), D18.4 (VDD), D19.4 (VDD), D20.4 (VDD), D21.4 (VDD), D22.4 (VDD), D23.4 (VDD), D24.4 (VDD), D25.4 (VDD), D26.4 (VDD), D27.4 (VDD), D28.4 (VDD), D29.4 (VDD), D30.4 (VDD), D31.4 (VDD), D32.4 (VDD), D33.4 (VDD), D34.4 (VDD), D35.4 (VDD), D36.4 (VDD), D37.4 (VDD), D38.4 (VDD), D39.4 (VDD), D40.4 (VDD), D41.4 (VDD), D42.4 (VDD), D43.4 (VDD), D44.4 (VDD), D45.4 (VDD), D46.4 (VDD), D47.4 (VDD), D48.4 (VDD), D49.4 (VDD), D50.4 (VDD), D51.4 (VDD), D52.4 (VDD), D53.4 (VDD), D54.4 (VDD), D55.4 (VDD), D56.4 (VDD), D57.4 (VDD), D58.4 (VDD), D59.4 (VDD), D60.4 (VDD), D61.4 (VDD), D62.4 (VDD), D63.4 (VDD), D64.4 (VDD); also elsewhere on the board

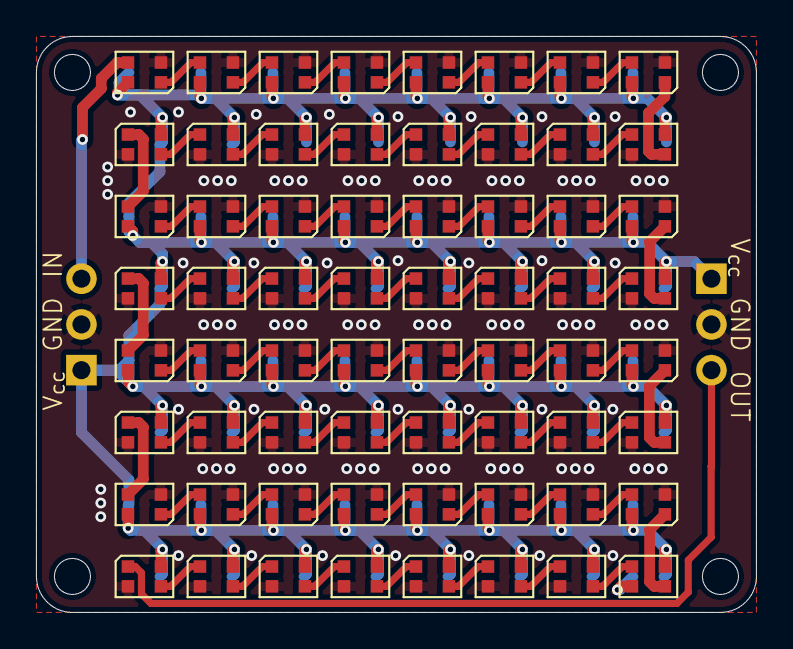
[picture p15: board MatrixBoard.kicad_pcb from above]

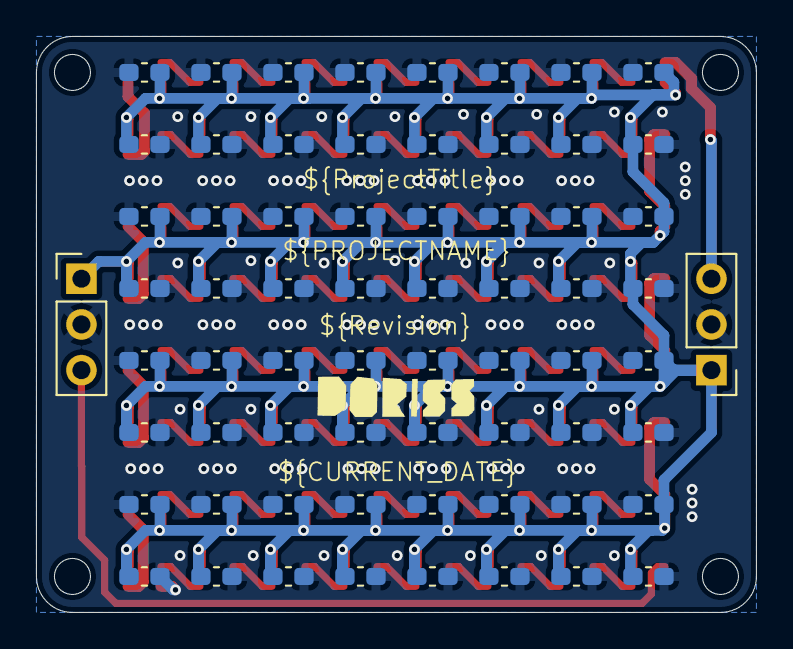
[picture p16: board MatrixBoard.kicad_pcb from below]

Board: 2 copper layers, 40.0 x 32.0 mm, 130 parts (66 on the bottom side), 67 nets.

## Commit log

2025-10-03 chore: Initial commit
    [CPU.kicad_sch, PowerBoard.kicad_pcb, PowerBoard.kicad_sch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]
2025-10-18 change revision
    [CPU.kicad_sch, mainboard.kicad_sch, pwr_ctr.kicad_sch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]
2025-10-18 change schematic, use touch controller to enable second bard power. microcontroller should set pin up to latch power
    [CPU.kicad_sch, PowerBoard.kicad_sch, mainboard.kicad_sch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]
2025-10-19 prepare matrix board
    [MatrixBoard.kicad_pcb, MatrixBoard.kicad_sch]
2025-10-19 Change location of tuch sensor, touch button now power up all components, change length. Add buzzer to mainboard and remove touch from them. change revision version
    [CPU.kicad_sch, PowerBoard.kicad_pcb, PowerBoard.kicad_sch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]
2025-10-19 add buzer, update layout to schematic, make pcb mounting
    [PowerBoard.kicad_pcb, mainboard.kicad_pcb, mainboard_0_4_0.step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]
2025-11-11 add matrix board, change pico to esp32 microcontroller
    [MatrixBoard.kicad_pcb, MatrixBoard.kicad_sch, Row.kicad_sch]
2025-11-11 some changes for esp32 board
    [CPU.kicad_sch, mainboard.kicad_pcb, mainboard.kicad_sch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]
2025-11-11 change schematic
    [CPU.kicad_sch, MatrixBoard.step, mainboard.kicad_pcb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]
2025-11-22 Change project assumptions, create new board with esp32-c3
    [CPU.kicad_sch, MatrixBoard.kicad_pcb, mainboard.kicad_pcb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]
2025-11-22 Udpate project variables and add texts
    [CPU.kicad_sch, MatrixBoard.kicad_pcb, mainboard.kicad_pcb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]
2025-11-22 Change naming of project
    [CPU.kicad_sch, mainboard.kicad_pcb, mainboard.kicad_sch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]
2025-11-22 rename 3d models
    [VirtualBlob_MainBoard_0.0.0.step, VirtualBlob_MainBoard_0.3.0.step, VirtualBlob_MainBoard_0.4.0.step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]
2025-11-22 add new spring touch
    [MatrixBoard.kicad_pcb, MatrixBoard.kicad_sch, Row.kicad_sch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]
2025-11-23 Add logo and update project variables
    [MatrixBoard.kicad_pcb, MatrixBoard.kicad_sch, Row.kicad_sch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]
2025-11-23 clean project, change location of some libraries
    [CPU.kicad_sch, PowerBoard.kicad_pcb, PowerBoard.kicad_sch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]
2025-11-23 Change some opto signals
    [mainboard.kicad_pcb, mainboard.kicad_sch, utils.kicad_sch]
